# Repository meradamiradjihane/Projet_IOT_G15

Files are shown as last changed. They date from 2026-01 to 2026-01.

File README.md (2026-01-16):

# Projet IoT - API RESTful sur TTGO T-Display ESP32

## Description

Système de surveillance de température et luminosité avec API RESTful implémentée sur microcontrôleur ESP32 TTGO T-Display. Le système permet la lecture de capteurs, le contrôle de LEDs et la configuration de seuils d'alerte via HTTP.

##  Matériel Requis

### Microcontrôleur
- **TTGO T-Display ESP32** avec écran TFT intégré (135x240 pixels)

### Capteurs
- **NTC Thermistor** (EPCOS B57861S, 10kΩ @ 25°C, β=3988K)
- **LDR** (photorésistance)

### Composants
- 4× LEDs (2 rouges, 2 vertes)
- 2× Résistances 1kΩ (pour LEDs et LDR)
- 1× Résistance 47kΩ (pour NTC)
- Câbles de connexion
- Breadboard

### Kit 
[Adafruit Kit #2975](https://www.adafruit.com/product/2975)

##  Schéma de Câblage

Pour faire le cablage nous avons utiliser Fri

```
ESP32 Pin Assignments:
├── GPIO 36 (ADC1_CH0) ← LDR (pont diviseur avec R=1kΩ)
├── GPIO 39 (ADC1_CH3) ← NTC (pont diviseur avec R=47kΩ)
├── GPIO 12 ← LED Rouge Température
├── GPIO 13 ← LED Verte Température
├── GPIO 2  ← LED Rouge Luminosité
├── GPIO 15 ← LED Verte Luminosité
├── GPIO 0  ← Bouton Gauche (intégré TTGO)
└── GPIO 35 ← Bouton Droit (intégré TTGO)
```
Le diagramme de câblage ci-dessous a été conçu avec Fritzing :

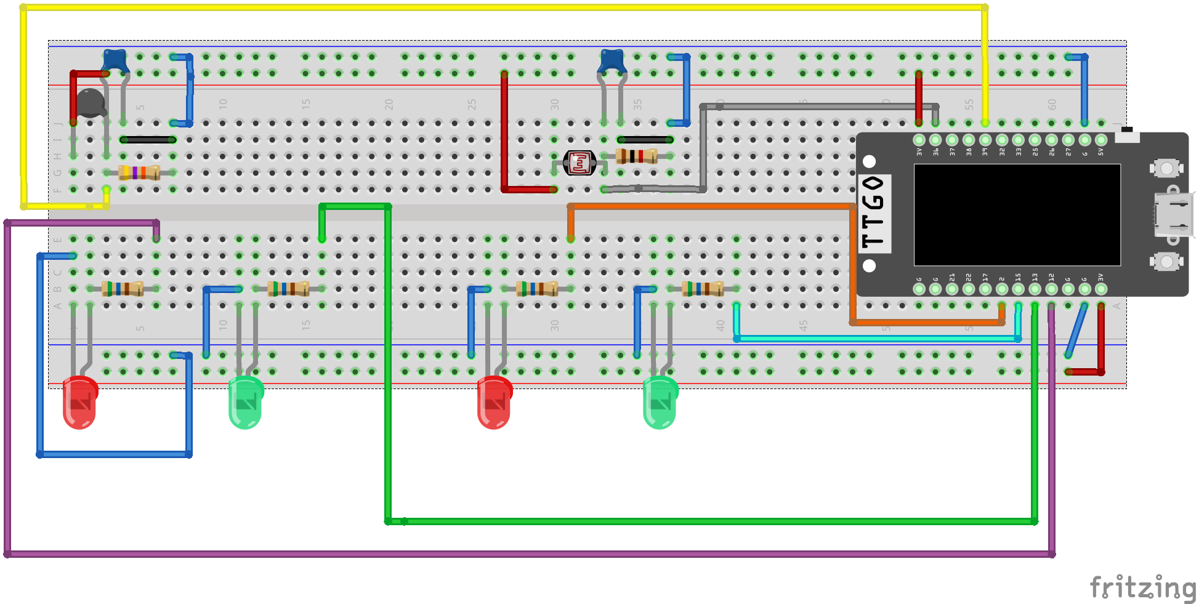
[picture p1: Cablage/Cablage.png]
Schéma de câblage


*Fichier source : [projet_iot.fzz](./Cablage/Pr_iot.fzz)*

### Ponts Diviseurs

**NTC (Température):**
```
3.3V ──[R_fix=47kΩ]── Vout (GPIO39) ──[NTC]── GND
```

**LDR (Luminosité):**
```
3.3V ──[R_fix=1kΩ]── Vout (GPIO36) ──[LDR]── GND
```

## Installation

### 1. Configuration Arduino IDE

1. Installer [Arduino IDE](https://www.arduino.cc/en/software)
2. Ajouter le support ESP32:
   - `Fichier` → `Préférences` → `URL de gestionnaire de cartes`
   - Ajouter: `https://dl.espressif.com/dl/package_esp32_index.json`
3. Installer la carte ESP32:
   - `Outils` → `Type de carte` → `Gestionnaire de cartes`
   - Chercher "ESP32" et installer

### 2. Bibliothèques Requises

Installer via `Croquis` → `Inclure bibliothèque` → `Gérer les bibliothèques`:

- **TFT_eSPI** (version ≥2.5.0)
- **ArduinoJson** (version ≥6.0.0)
- **WiFi** (intégré ESP32)
- **WebServer** (intégré ESP32)

### 3. Configuration TFT_eSPI

Éditer `Arduino/libraries/TFT_eSPI/User_Setup_Select.h`:
```cpp
// Commenter la ligne par défaut:
// #include <User_Setup.h>

// Décommenter la ligne TTGO T-Display:
#include <User_Setups/Setup25_TTGO_T_Display.h>
```

### 4. Configuration WiFi

Modifier dans `Projet_iot.ino`:
```cpp
const char* ssid     = "VOTRE_SSID";
const char* password = "VOTRE_MOT_DE_PASSE";
```

### 5. Téléversement

1. Connecter le TTGO T-Display via USB
2. Sélectionner:
   - `Outils` → `Type de carte` → `TTGO T1`
   - `Outils` → `Upload speed` → `115200`
   - `Outils` → `Port` → (sélectionner le port USB)
3. Cliquer sur `Téléverser`

##  API RESTful - Endpoints ESP32

### Lister les Capteurs
```http
GET http://<ESP32_IP>/sensors
```
**Réponse:**
```json
{
  "sensors": ["ldr", "thermistor"]
}
```

### Lire la Température
```http
GET http://<ESP32_IP>/temp
```
**Réponse:**
```json
{
  "raw": 2048,
  "voltage": 1.65,
  "celsius": 23.5
}
```

### Lire la Luminosité
```http
GET http://<ESP32_IP>/ldr
```
**Réponse:**
```json
{
  "raw": 1500,
  "voltage": 1.21,
  "res_ohm": 450.5
}
```

### Configurer les Seuils de Température
```http
GET http://<ESP32_IP>/config/temp?min=15&max=28
```
**Réponse:**
```json
{
  "TEMP_MIN": 15.0,
  "TEMP_MAX": 28.0
}
```

### Configurer le Seuil de Luminosité
```http
GET http://<ESP32_IP>/config/ldr?min=50
```
**Réponse:**
```json
{
  "rLdr_MIN": 50.0
}
```

## Interface Utilisateur

### Écran TFT
Affiche en temps réel:
- Température (en °C)
- Résistance LDR (en Ω)
- Rafraîchissement: 1 fois/seconde

### LEDs Indicatrices

| LED | Couleur | Condition |
|-----|---|---|
| Température | 🟢 Verte | TEMP_MIN ≤ T ≤ TEMP_MAX |
| Température | 🔴 Rouge | T < TEMP_MIN ou T > TEMP_MAX |
| Luminosité | 🟢 Verte | R_LDR ≥ R_MIN |
| Luminosité | 🔴 Rouge | R_LDR < R_MIN |

### Boutons (TTGO T-Display)
 **Bouton Gauche (GPIO 0):**
 **Bouton Droit (GPIO 35):**

##  Formules de Calcul

### Conversion ADC → Tension
```
V_out = (ADC_raw × V_ref) / ADC_max
```
Avec: V_ref = 3.3V, ADC_max = 4095 (12 bits)

### Résistance NTC
```
R_NTC = R_fix × (V_ref - V_out) / V_out
```

### Température (Équation de Steinhart-Hart simplifiée)
```
1/T = (1/T₀) + (1/β) × ln(R_NTC / R₀)
T_celsius = T - 273.15
```
Avec: T₀ = 298.15K (25°C), β = 3988K, R₀ = 10kΩ

### Résistance LDR

```
R_LDR = R_fix × V_out / (V_ref - V_out)
```

##  Tests
 Pour les teste nous avon cree une autre API en python utilisant le framework FastAPI l'application permet de tester les endpoints de l'API RESTful de l'ESP32.

##  API Python (FastAPI)

### Installation
```bash
pip install -r requirements.txt
```

### Configuration
Modifier `API.py`:
```python
ESP32_IP = "http://<VOTRE_IP_ESP32>"
```

### Lancement
```bash
uvicorn API:app --reload --host 0.0.0.0 --port 8000
```

## Groupe 15 
Auteurs: 

MERAD Amira Djihane
CHBOUK Yassir
AMARA Rafik
Goussem Ayoub

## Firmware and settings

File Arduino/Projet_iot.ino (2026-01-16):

#include <WiFi.h>
#include <WebServer.h>
#include <ArduinoJson.h>
#include <TFT_eSPI.h>
#include <math.h>

// ===== WIFI =====
const char* ssid     = "VOTRE_SSID";
const char* password = "VOTRE_MOT_DE_PASSE";

#define PIN_LDR   36
#define PIN_NTC   39

#define LED_TEMP_RED    12
#define LED_TEMP_GREEN  13
#define LED_LDR_RED     2
#define LED_LDR_GREEN   15

// ===== ADC =====
static const float VREF = 3.3f;
static const int   ADC_MAX = 4095;
  
// ===== PONTS DIVISEURS =====
static const float R_FIXED_LDR = 1000.0f;
static const float R_FIXED_NTC = 47000.0f;

// ===== NTC =====
static const float R_25     = 10000.0f;
static const float B_25_100 = 3988.0f;
static const float T_25_K   = 298.15f;


float TEMP_MIN = 10.0f;
float TEMP_MAX = 30.0f;
float rLdr_MIN = 20.0f;

bool manualMode = false;


WebServer server(80);
TFT_eSPI tft = TFT_eSPI();


float adcToVoltage(int raw) {
  return (raw * VREF) / ADC_MAX;
}

float ntcResistanceFromVout(float vout) {
  if (vout <= 0.01f || vout >= (VREF - 0.01f)) return NAN;
  return R_FIXED_NTC * ((VREF - vout) / vout);
}

float ntcToCelsius(float vout) {
  float rNtc = ntcResistanceFromVout(vout);
  if (isnan(rNtc) || rNtc <= 0.0f) return NAN;

  float invT = (1.0f / T_25_K) +
               (1.0f / B_25_100) * log(rNtc / R_25);
  return (1.0f / invT) - 273.15f;
}

float ldrResistanceFromVout(float vout) {
  if (vout <= 0.001f || vout >= (VREF - 0.001f)) return NAN;
  return R_FIXED_LDR * (vout / (VREF - vout));
}

void handleSensors() {
  server.send(200, "application/json",
              "{\"sensors\":[\"ldr\",\"thermistor\"]}");
}

void handleLdr() {
  int raw = analogRead(PIN_LDR);
  float v = adcToVoltage(raw);
  float r = ldrResistanceFromVout(v);

  StaticJsonDocument<128> doc;
  doc["raw"] = raw;
  doc["voltage"] = v;
  if (!isnan(r)) doc["res_ohm"] = r;

  String out;
  serializeJson(doc, out);
  server.send(200, "application/json", out);
}

void handleTemp() {
  int raw = analogRead(PIN_NTC);
  float v = adcToVoltage(raw);
  float c = ntcToCelsius(v);

  StaticJsonDocument<128> doc;
  doc["raw"] = raw;
  doc["voltage"] = v;
  if (!isnan(c)) doc["celsius"] = c;

  String out;
  serializeJson(doc, out);
  server.send(200, "application/json", out);
}

void handleTempConfig() {
  if (server.hasArg("min")) TEMP_MIN = server.arg("min").toFloat();
  if (server.hasArg("max")) TEMP_MAX = server.arg("max").toFloat();

  StaticJsonDocument<128> doc;
  doc["TEMP_MIN"] = TEMP_MIN;
  doc["TEMP_MAX"] = TEMP_MAX;

  String out;
  serializeJson(doc, out);
  server.send(200, "application/json", out);
}

void handleLDRConfig() {
  if (server.hasArg("min")) rLdr_MIN = server.arg("min").toFloat();

  StaticJsonDocument<128> doc;
  doc["rLdr_MIN"] = rLdr_MIN;

  String out;
  serializeJson(doc, out);
  server.send(200, "application/json", out);
}

void handleLedManual() {
  if (!server.hasArg("id") || !server.hasArg("state")) {
    server.send(400, "application/json", "{\"error\":\"missing args\"}");
    return;
  }

  manualMode = true;

  String id = server.arg("id");
  String state = server.arg("state");

  auto apply = [&](int pin) {
    if (state == "on") digitalWrite(pin, HIGH);
    else if (state == "off") digitalWrite(pin, LOW);
    else if (state == "toggle") digitalWrite(pin, !digitalRead(pin));
  };

  if (id == "1R") apply(LED_TEMP_RED);
  else if (id == "1V") apply(LED_TEMP_GREEN);
  else if (id == "2R") apply(LED_LDR_RED);
  else if (id == "2V") apply(LED_LDR_GREEN);
  else if (id == "all") {
    apply(LED_TEMP_RED);
    apply(LED_TEMP_GREEN);
    apply(LED_LDR_RED);
    apply(LED_LDR_GREEN);
  } else {
    server.send(400, "application/json", "{\"error\":\"unknown led\"}");
    return;
  }

  server.send(200, "application/json", "{\"mode\":\"manual\"}");
}

void handleMode() {
  if (server.hasArg("set")) {
    manualMode = (server.arg("set") == "manual");
  }

  StaticJsonDocument<64> doc;
  doc["mode"] = manualMode ? "manual" : "auto";

  String out;
  serializeJson(doc, out);
  server.send(200, "application/json", out);
}

// ===== SETUP =====
void setup() {
  Serial.begin(115200);

  pinMode(LED_TEMP_RED, OUTPUT);
  pinMode(LED_TEMP_GREEN, OUTPUT);
  pinMode(LED_LDR_RED, OUTPUT);
  pinMode(LED_LDR_GREEN, OUTPUT);

  analogReadResolution(12);
  analogSetPinAttenuation(PIN_LDR, ADC_11db);
  analogSetPinAttenuation(PIN_NTC, ADC_11db);

  tft.init();
  tft.setRotation(1);
  tft.fillScreen(TFT_BLACK);
  tft.setTextColor(TFT_WHITE);

  WiFi.begin(ssid, password);
  while (WiFi.status() != WL_CONNECTED) delay(300);
  
  Serial.println("\nWiFi connected");
  Serial.println(WiFi.localIP());


  server.on("/sensors", handleSensors);
  server.on("/ldr", handleLdr);
  server.on("/temp", handleTemp);
  server.on("/config/temp", handleTempConfig);
  server.on("/config/ldr", handleLDRConfig);
  server.on("/led", handleLedManual);   
  server.on("/mode", handleMode);      

  server.begin();
}


void loop() {
  server.handleClient();

  float tempC = ntcToCelsius(adcToVoltage(analogRead(PIN_NTC)));
  float rLdr  = ldrResistanceFromVout(adcToVoltage(analogRead(PIN_LDR)));
  
--
  if (!manualMode) {
    if (!isnan(tempC) && (tempC < TEMP_MIN || tempC > TEMP_MAX)) {
      digitalWrite(LED_TEMP_RED, HIGH);
      digitalWrite(LED_TEMP_GREEN, LOW);
    } else {
      digitalWrite(LED_TEMP_RED, LOW);
      digitalWrite(LED_TEMP_GREEN, HIGH);
    }

    if (isnan(rLdr) || rLdr < rLdr_MIN) {
      digitalWrite(LED_LDR_RED, HIGH);
      digitalWrite(LED_LDR_GREEN, LOW);
    } else {
      digitalWrite(LED_LDR_RED, LOW);
      digitalWrite(LED_LDR_GREEN, HIGH);
    }
  }

  tft.setCursor(0, 0);
  tft.fillRect(0, 0, 240, 135, TFT_BLACK);
  tft.printf("Mode: %s\n", manualMode ? "MANUEL" : "AUTO");
  tft.printf("Temp: %.2f C\n", tempC);
  tft.printf("LDR: %.0f ohm\n", rLdr);

  delay(400);
}

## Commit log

2026-01-16 upload project
    [Pr_iot.fzz]
2026-01-16 Update wiring diagram image path in README.md
